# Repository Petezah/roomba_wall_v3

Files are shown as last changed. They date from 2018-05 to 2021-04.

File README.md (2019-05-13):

# roomba_wall_v3

An AVR device, based on ATTiny45, to transmit a virtual wall signal for an iRobot Roomba

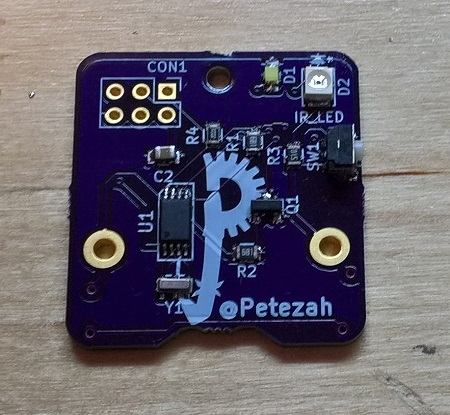
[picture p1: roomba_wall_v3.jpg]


## Folder layout

* /firmware
  * Source for the ATTiny45 firmware
* /hardware
  * Files describing the board layout, etc

## Building

### Prerequisites for "happy path":

* An AVR programmer
  * If you don't have one, you can build mine: https://oshpark.com/shared_projects/O24XLDbo
  * Though, this is a chicken-egg problem.  You can always program the programmer with an Arduino or a Raspberry Pi.
* AVR-GCC installed
  *  Easiest way to get this is 'sudo apt-get install arduino'
* A 6-position, dual-row IDC cable
* A 6-position, dual-row, male header to either:
  * Solder onto your board for programming, or
  * Plug into the IDC cable and "wedge" it into the ISP header during programming (recommended, and is what I do)

### Steps

#### hardware

* Order a board based on the files in https://github.com/Petezah/roomba_wall_v3/tree/master/hardware
  * Alternately, order one directly from OSH Park here: https://oshpark.com/shared_projects/i2FdXslA
* Purchase parts from [Mouser electronics](http://mouser.com) using the current BOM
  * Use the ones with "mouser" in their filenames
* Assemble the board--part references are all marked on the silkscreen
  * NB: The ISP header should not be soldered to the board--merely insert the header pins into the IDC cable and wedge the pins into the vias during programming

#### firmware

There are two methods to wire the board for programming:

* *Recommended way*:
  *  Order my AVR programmer board here: https://oshpark.com/shared_projects/O24XLDbo
  *  Assemble, and use an IDC cable as described above

* Alternate way: 
  *  Order my Raspberry Pi ISP board here: https://oshpark.com/shared_projects/iYtnPahC
  * Or hook up the ISP pins on the assembled board to your Raspberry PI as follows:
    * ISP Pin 1 --> Raspberry Pi Pin 21 (MISO)
    * ISP Pin 2 --> Raspberry Pi Pin 17 (3.3V)
    * ISP Pin 3 --> Raspberry Pi Pin 23 (SCK)
    * ISP Pin 4 --> Raspberry Pi Pin 19 (MOSI)
    * ISP Pin 5 --> Raspberry Pi Pin 15 (GPIO22)
    * ISP Pin 6 --> Raspberry Pi Pin 25 (GND)

Once wiring is accomplished:
* Execute the following on the Raspberry Pi command line
  * cd firmware
  * make fuse
  * make install

## Operating

There are a few different ways to operate this device.

### Default (easy) timed mode

When the device is off (sleeping), simply press and release the button once.  The device will respond by turning the indicator LED on for one second and then turning it off.  After this, the device will operate for 3 hours and then go to sleep again.

### Custom timed mode

When the device is off (sleeping), hold down the button.  The device will blink briefly, once every half second.  Every blink corresponds to 15 minutes of operation.  For example, if you want the device to operate for 30 minutes, you will wait for 2 blinks; or, if you want the device to operate for 1 hour and 15 minutes, you will wait for 5 blinks.  Once you reach the desired count, release the button.  The device will then wait, and will then blink the LED indicator the number of times it has counted for the running time.  After this, the device will run for the set time, and then will go to sleep.

### Turning off the device (putting it to sleep manually)

When the device is operating, hold down the button for two seconds.  The device will blink 3 times rapidly.  Now release the button, and the device will blink 2 times rapidly, and will then go to sleep.

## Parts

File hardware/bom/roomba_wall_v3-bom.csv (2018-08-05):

Reference | Value | Footprint | Datasheet
U1 | ATTINY45-20SU | lib_fp:ATtiny45V-10XU-TSSOP-8
Y1 | 8Mhz | lib_fp:Resonator_SMD_muRata_CSTCE_G-3pin_3.0x0.7mm
R1 | 560 | lib_fp:R_0805
R2 | 560 | lib_fp:R_0805
R3 | 51 | lib_fp:R_0805
D1 | LED | lib_fp:LED_0805
D2 | IR_LED | kicad-libs:VSMB3940X01-GS08
CON1 | AVR-ISP-6 | lib_fp:Pin_Header_Straight_2x03_Pitch2.54mm
C2 | 10uF | lib_fp:C_0805
Q1 | Q_NPN_BEC | lib_fp:SOT-23
BT1 | Battery_Cell | lib_fp:CR2032-THRU
SW1 | Button | lib_fp:e-switch-TL-3340-AF160QG
R4 | 10k | lib_fp:R_0805

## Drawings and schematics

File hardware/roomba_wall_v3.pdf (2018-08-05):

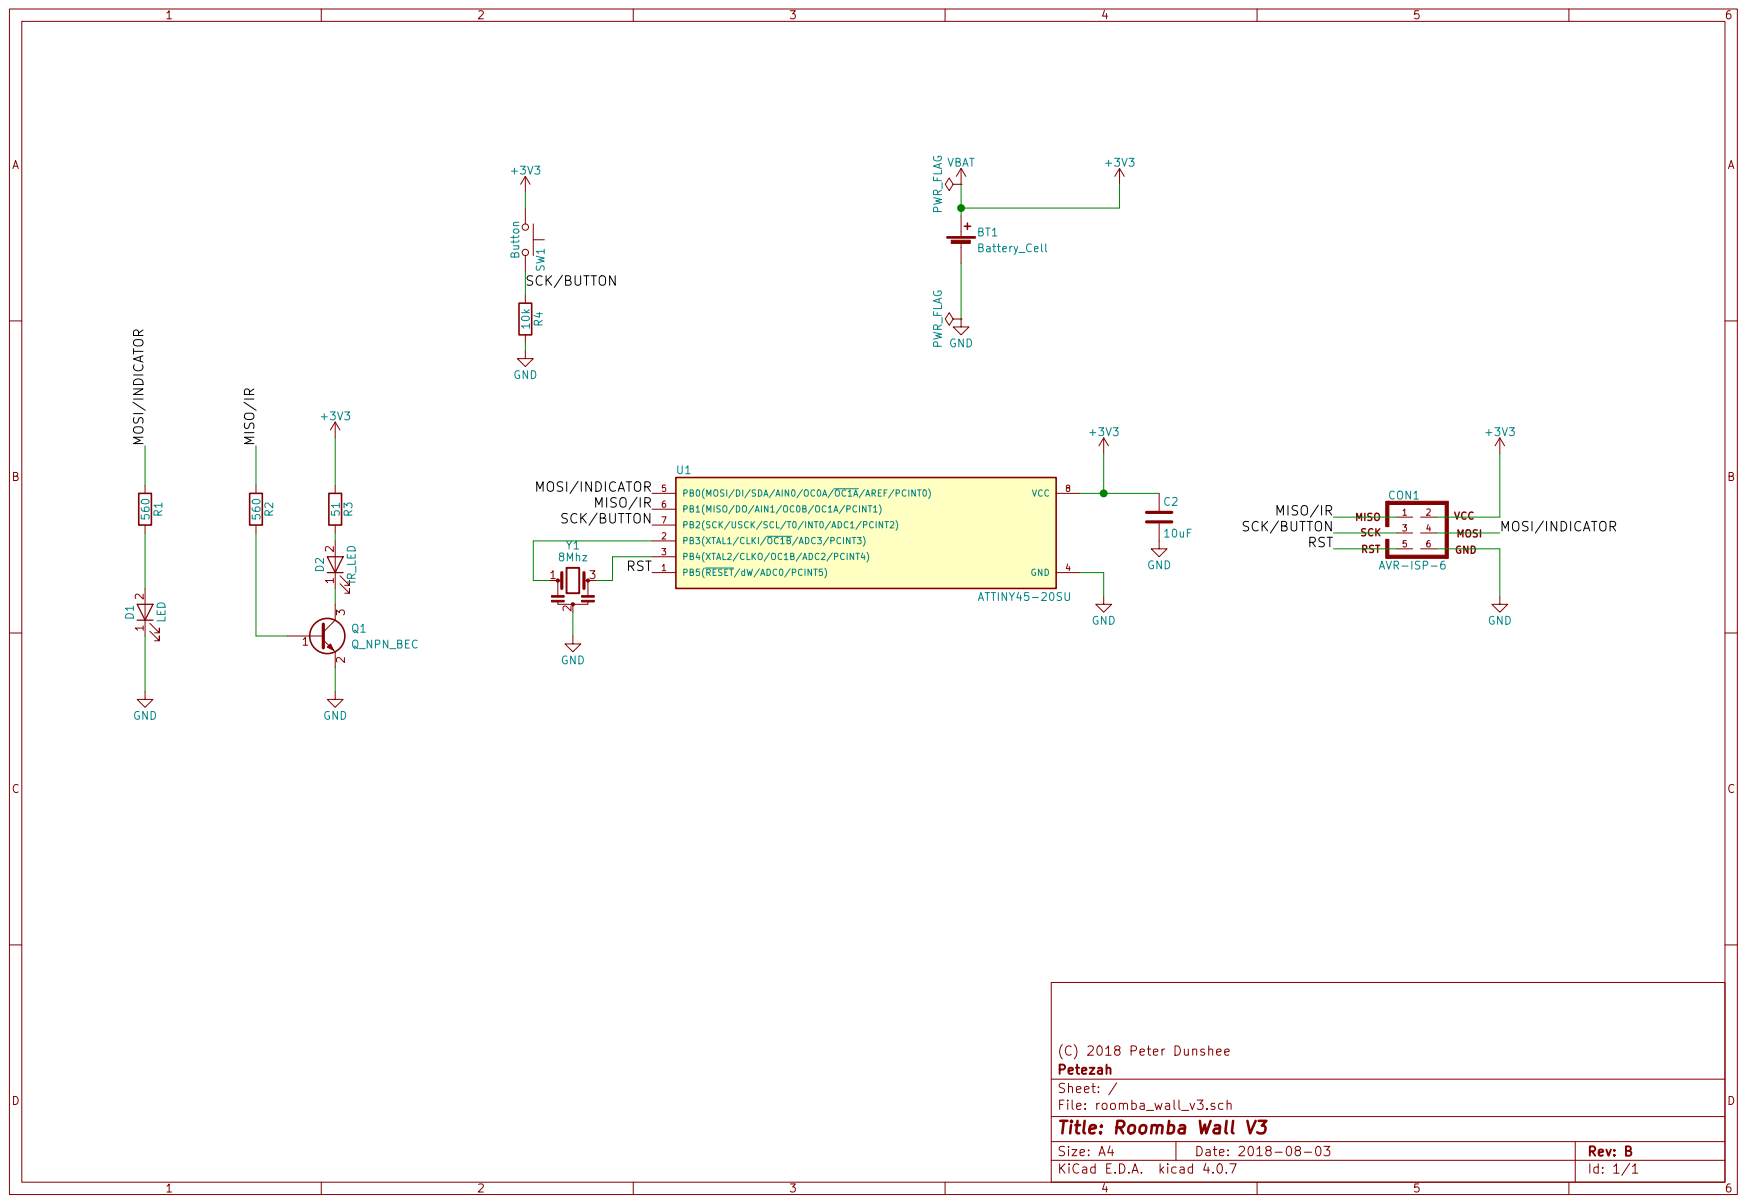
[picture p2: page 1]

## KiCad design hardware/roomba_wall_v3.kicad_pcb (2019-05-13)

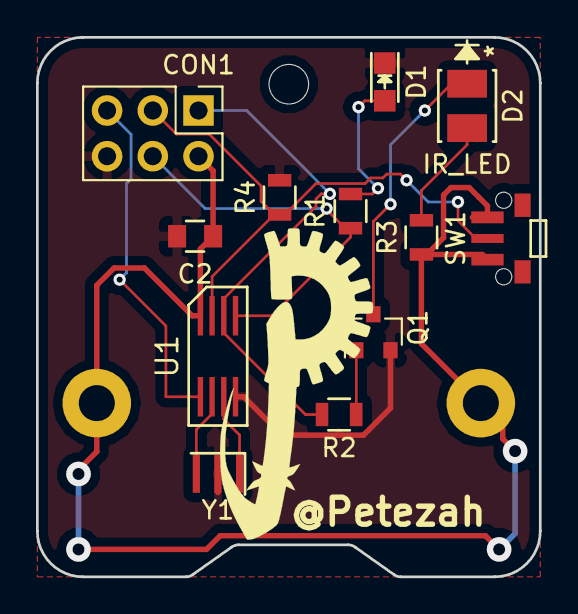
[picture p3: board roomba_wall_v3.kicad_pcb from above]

Board: 2 copper layers, 27.9 x 30.0 mm, 13 parts (1 on the bottom side), 12 nets.

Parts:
BT1: Battery_Cell; CR2032-THRU
C2: 10uF; C_0805
CON1: AVR-ISP-6; Pin_Header_Straight_2x03_Pitch2.54mm
D1: LED; LED_0805
D2: IR_LED; VSMB3940X01-GS08
Q1: Q_NPN_BEC; SOT-23
R1, R2: 560; R_0805
R3: 51; R_0805
R4: 10k; R_0805
SW1: Button; e-switch-TL-3340-AF160QG
U1: ATTINY45-20SU; ATtiny45V-10XU-TSSOP-8
Y1: 8Mhz; Resonator_SMD_muRata_CSTCE_G-3pin_3.0x0.7mm

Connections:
+3V3: BT1.1, C2.1, CON1.2, R3.1, SW1.1, U1.8
/MISO/IR: CON1.1, R2.1, U1.6
/MOSI/INDICATOR: CON1.4, R1.1, U1.5
/RST: CON1.5, U1.1
/SCK/BUTTON: CON1.3, R4.1, SW1.2, U1.7
GND: BT1.2, C2.2, CON1.6, D1.1, Q1.2, R4.2, U1.4, Y1.2
unnamed: D1.2, R1.2
unnamed: D2.1, Q1.3
unnamed: D2.2, R3.2
unnamed: Q1.1, R2.2
unnamed: U1.2, Y1.1
unnamed: U1.3, Y1.3

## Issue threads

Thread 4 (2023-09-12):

No BOM for mouser

ahshah, 2023-09-12:
Hi, thanks for making this project available to us- there is no mouser BOM, and the CSV in the bom folder does not contain part numbers. Would this be a mistaken omission or am i reading the readme incorrectly?
Thanks!

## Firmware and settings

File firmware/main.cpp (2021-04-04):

/*
 * roomba_wall_v2.cpp
 *
 * Created: 5/11/2016 9:12:04 PM
 * Author : Peter Dunshee
 */

#include "roomba_wall_v3.h"
#include <avr/io.h>
#include <avr/power.h>
#include <avr/interrupt.h>
#include <avr/sleep.h>
#include <avr/wdt.h>
#include <util/delay.h>

enum run_state
{
	RS_Sleeping = 0,	// device sleeping
	RS_Running,			// running, normal
	RS_RunningShutdown, // running, in possible shut-down process
	RS_ShuttingDown,	// shutdown initiated, debouncing switch before sleep
	RS_InitCounter,		// start-up, init the counter process
	RS_Counter,			// running the counter process
	RS_TimeSet			// setting the timer, proceeds to running state
};
volatile run_state g_state = RS_Sleeping;   // current state-machine state
volatile uint32_t g_timerTicks = 0;			// number of TIMER1 ticks since power-on
volatile uint32_t g_lastTimerTicks = 0;		// used to time operations in various places
volatile int g_counter = 0;					// saves the state-counter value between iterations
volatile uint8_t g_debounceDownCounter = 0; // how long the button has been depressed
volatile uint8_t g_debounceUpCounter = 0;   // how long the button has been released
volatile uint8_t g_setTimeCount = 0;		// records the number of time units the user has set the device to run for

#ifdef HALF_HOUR_PER_BLINK
#define NUM_TIMER_TICKS_PER_PRESS 3600; // run for 1/2hr per setting: 3600 = 60s * 30m * 2, since 1 tick per .5s
#else									// QUARTER_HOUR_PER_BLINK
#define NUM_TIMER_TICKS_PER_PRESS 1800; // run for 1/4hr per setting: 1800 = 60s * 15m * 2, since 1 tick per .5s
#endif
#define DEFAULT_NUM_TICKS_UNTIL_DISABLED (2 /*hours*/ * 60 /*minutes*/ * 60 /*seconds*/ * 2 /*seconds per tick*/)
volatile int g_numTicksUntilDisabled = 0;

#ifdef ROOMBA_WALL_V2
#define IR_TX_DELAY 50000
#elif ROOMBA_WALL_V3
#define IR_TX_DELAY 25000
#else // others (eg. Christmas barrier)
#define IR_TX_DELAY 10000
#endif

// 4s watchdog timeout
#define ROOMBA_WALL_WDT_VALUE WDTO_4S

void sleep_until_interrupt()
{
	wdt_disable();      // disable watchdog
	MCUCR |= _BV(SE);   // sleep enable bit
	GIMSK |= _BV(PCIE); // Enable pin-change interrupts to wake us up
	sleep_mode();
	GIMSK &= ~_BV(PCIE); // Disable pin-change interrupts
	MCUCR &= ~_BV(SE);   // clear sleep enable bit
	wdt_enable(ROOMBA_WALL_WDT_VALUE);
}

void blink_led(uint8_t numTimes, bool fastDelay = false)
{
	PORTB &= ~_BV(0);
	for (uint8_t i = 0; i < numTimes; ++i)
	{
		if (fastDelay)
			_delay_ms(50);
		else
			_delay_ms(200);
		PORTB |= _BV(0); //on
		if (fastDelay)
			_delay_ms(50);
		else
			_delay_ms(200);
		PORTB &= ~_BV(0); //off
	}
}

int main(void)
{
	// Disable ADC; we don't need it, and it uses more power
	ACSR |= _BV(ACD); // analog comparator disable

	// Set up timer1 to trigger every 1/2 second
	TCCR1 |= _BV(CTC1);										// enable timer compare match CTC1
	TCCR1 |= _BV(CS13) | _BV(CS12) | _BV(CS11) | _BV(CS10); // set prescaler ck/16384 (1/(8Mhz/16384) = 2.048 ms)
	OCR1C = 244;											// count to 1/2 seconds (2.048ms * 244 = .5s)
	TIMSK |= _BV(OCIE1A);									// enable compare match irq

	// Set interrupt on PB2
	DDRB &= ~_BV(DDB2);					// PB2 set as input
	GIMSK |= _BV(INT0);					// enable PCIE interrupt
	PCMSK |= _BV(PCINT2);				// interrupt on PB2
	MCUCR |= (_BV(ISC01) | _BV(ISC00)); // enable rising edge (ISC01 and ISC00)
	MCUCR |= _BV(SM1);					// enable power-down for sleep (SM1)
	sei();								// enable interrupts

	// Red-Status LED
	DDRB |= _BV(0);   // Set PORTB pin 4 to digital output (equivalent to pinMode(0, OUTPUT))
	PORTB &= ~_BV(0); // Pin 0 set to LOW (equivalent to digitalWrite(0, LOW))

#ifdef ROOMBA_WALL_V3
	// Power down initially
	g_state = RS_Sleeping;
	sleep_until_interrupt();
#else
	g_state = RS_Running;
#endif

	g_counter = -1;
	int i = -1;
	uint32_t lastBlinkTick = 0;
	while (1)
	{
		wdt_reset();
		i = g_counter;
		switch (g_state)
		{
		case RS_Sleeping:
			g_setTimeCount = 0;
			sleep_until_interrupt();
			break;

		case RS_ShuttingDown:
			if (g_debounceUpCounter >= 2)
			{
				blink_led(2, true);
				g_state = RS_Sleeping;
				delay_ten_us(1000);
				g_debounceDownCounter = 0;
				g_debounceUpCounter = 0;
				i = 0;
			}
			break;

		case RS_RunningShutdown:
			// If the button has been pressed for more than 2 seconds,
			// blink, then shut down the device
			if (g_debounceDownCounter >= 4)
			{
				blink_led(3, true);
				g_state = RS_ShuttingDown;
				g_debounceUpCounter = 0;
				g_debounceDownCounter = 0;
				i = 0;
			}
			// If the button has been released long enough, revert to Running state
			if (g_debounceUpCounter >= 2)
			{
				g_state = RS_Running;
				g_debounceDownCounter = 0;
				g_debounceUpCounter = 0;
				i = 0;
			}
			// Fall through to RS_Running
		case RS_Running:
			if (g_numTicksUntilDisabled <= 0)
				g_state = RS_Sleeping;

			g_setTimeCount = 0;
			i++;
			if (i == 0)
				PORTB |= _BV(0); // digitalWrite(4, HIGH);
			if (i == 1)
				PORTB &= ~_BV(0); // digitalWrite(4, LOW);
			if (i == 5)
				i = -1;

			roomba_send(162); // Virtual Wall
			PORTB &= ~_BV(0); // digitalWrite(4, LOW);

			delay_ten_us(IR_TX_DELAY);
			break;
		case RS_InitCounter:
			// Initialize the time setter and proceed to the counter phase
			g_state = RS_Counter;
			lastBlinkTick = g_lastTimerTicks;
			break;

		case RS_Counter:
			i++;
			// If it has been more than 1 second (1 tick == .5s)
			// indicate to the user that another "count" has happened
			if (g_timerTicks - lastBlinkTick >= 2)
			{
				lastBlinkTick = g_timerTicks;
				blink_led(1, true);
			}
			// If the button has been released for more than 1 second,
			// proceed to time-setting phase based on our current count
			if (g_debounceUpCounter >= 2)
			{
				g_setTimeCount = (g_timerTicks - g_lastTimerTicks) / 2;
				g_setTimeCount--; // adjust for fudge-error
				g_state = RS_TimeSet;
				i = 0;
			}
			break;

		case RS_TimeSet:
			if (g_setTimeCount < 1)
			{
				// Button was pressed and released; merely start the default timer
				g_numTicksUntilDisabled = DEFAULT_NUM_TICKS_UNTIL_DISABLED;
				g_state = RS_Running;

				// Turn on the LED for 1 second to indicate success of default state
				PORTB |= _BV(0); //on
				_delay_ms(1000);
				PORTB &= ~_BV(0); //off
				break;
			}

			i++;
			if (i >= 2) // 2 seconds
			{
				i = -1;
				g_state = RS_Running;
				blink_led(g_setTimeCount); // Indicate to the user how much time we have been actually set for
			}
			_delay_ms(2000);
			g_numTicksUntilDisabled = g_setTimeCount * NUM_TIMER_TICKS_PER_PRESS;
			break;
		} //switch

		g_counter = i;
	}
}

ISR(PCINT0_vect)
{
	// do nothing
}

ISR(INT0_vect)
{
	// If we are running, the button will turn off the device
	if (g_state == RS_Running)
	{
		g_counter = 0;
		g_debounceDownCounter = 0;
		g_debounceUpCounter = 0;
		g_lastTimerTicks = g_timerTicks;
		g_state = RS_RunningShutdown;
	}
	// If we are not already initializing or starting the
	// timer-set counter, then initialize the timer-setter
	else if (g_state != RS_InitCounter && g_state != RS_Counter && g_state != RS_RunningShutdown)
	{
		g_counter = 0;
		g_debounceDownCounter = 0;
		g_debounceUpCounter = 0;
		g_lastTimerTicks = g_timerTicks;
		g_state = RS_InitCounter;
	}
	PORTB &= ~_BV(0);
}

ISR(TIMER1_COMPA_vect)
{
	g_timerTicks++;
	g_numTicksUntilDisabled--;
	if (PINB & _BV(PB2))
		g_debounceDownCounter++;
	else
		g_debounceUpCounter++;
}

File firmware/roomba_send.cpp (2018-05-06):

/*

Send infrared commands from the Arduino to the iRobot Roomba
by probono

2013-03-17 Initial release

Copyright (c) 2013 by probono
All rights reserved.

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
1. Redistributions of source code must retain the above copyright notice, this
list of conditions and the following disclaimer.
2. Redistributions in binary form must reproduce the above copyright notice,
this list of conditions and the following disclaimer in the documentation
and/or other materials provided with the distribution.

THIS SOFTWARE IS PROVIDED BY THE COPYRIGHT HOLDERS AND CONTRIBUTORS "AS IS" AND
ANY EXPRESS OR IMPLIED WARRANTIES, INCLUDING, BUT NOT LIMITED TO, THE IMPLIED
WARRANTIES OF MERCHANTABILITY AND FITNESS FOR A PARTICULAR PURPOSE ARE
DISCLAIMED. IN NO EVENT SHALL THE COPYRIGHT OWNER OR CONTRIBUTORS BE LIABLE FOR
ANY DIRECT, INDIRECT, INCIDENTAL, SPECIAL, EXEMPLARY, OR CONSEQUENTIAL DAMAGES
(INCLUDING, BUT NOT LIMITED TO, PROCUREMENT OF SUBSTITUTE GOODS OR SERVICES;
LOSS OF USE, DATA, OR PROFITS; OR BUSINESS INTERRUPTION) HOWEVER CAUSED AND
ON ANY THEORY OF LIABILITY, WHETHER IN CONTRACT, STRICT LIABILITY, OR TORT
(INCLUDING NEGLIGENCE OR OTHERWISE) ARISING IN ANY WAY OUT OF THE USE OF THIS
SOFTWARE, EVEN IF ADVISED OF THE POSSIBILITY OF SUCH DAMAGE.

IR Remote Control
129 Left
130 Forward
131 Right
132 Spot
133 Max
134 Small
135 Medium
136 Large / Clean
137 Stop
138 Power
139 Arc Left
140 Arc Right
141 Stop

Scheduling Remote
142 Download
143 Seek Dock

Roomba Discovery Driveon Charger
240 Reserved
248 Red Buoy
244 Green Buoy
242 Force Field
252 Red Buoy and Green Buoy
250 Red Buoy and Force Field
246 Green Buoy and Force Field
254 Red Buoy, Green Buoy and Force

Roomba 500 Drive-on Charger
160 Reserved
161 Force Field
164 Green Buoy
165 Green Buoy and Force Field
168 Red Buoy
169 Red Buoy and Force Field
172 Red Buoy and Green Buoy
173 Red Buoy, Green Buoy and Force Field

Roomba 500 Virtual Wall
162 Virtual Wall

Roomba 500 Virtual Wall Lighthouse ###### (FIXME: not yet supported here)
0LLLL0BB
LLLL = Virtual Wall Lighthouse ID
(assigned automatically by Roomba
560 and 570 robots)
1-10: Valid ID
11: Unbound
12-15: Reserved
BB = Which Beam
00 = Fence
01 = Force Field
10 = Green Buoy
11 = Red Buoy

*/

#include "roomba_wall_v3.h"

void roomba_send(int code)
{
	const int length = 8;
	unsigned int raw[length * 2];
	unsigned int one_pulse = 3000;
	unsigned int one_break = 1000;
	unsigned int zero_pulse = one_break;
	unsigned int zero_break = one_pulse;

	int arrayposition = 0;
	// Serial.println("");
	for (int counter = length - 1; counter >= 0; --counter)
	{
		if (code & (1 << counter))
		{
			// Serial.print("1");
			raw[arrayposition] = one_pulse;
			raw[arrayposition + 1] = one_break;
		}
		else
		{
			// Serial.print("0");
			raw[arrayposition] = zero_pulse;
			raw[arrayposition + 1] = zero_break;
		}
		arrayposition = arrayposition + 2;
	}
	for (int i = 0; i < 3; i++)
	{
		sendRawIR(raw, 15, 38); //irsend.sendRaw(raw, 15, 38);  // Based on IRRemote library
		delay_ten_us(5000);			//50ms = 50000us
	}
	//Serial.println("");
}

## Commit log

2018-02-24 Allow the wake time to be set via a button hold
2018-02-25 Start v3 PCB project
    [roomba_wall_v2.brd, roomba_wall_v2.sch, roomba_wall_v2_c.brd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]
2018-02-25 Start v3 hardware from the Christmas tree barrier point
    [christmas_tree_barrier-B.Cu.gbr, christmas_tree_barrier-B.Mask.gbr, christmas_tree_barrier-B.Paste.gbr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]
2018-02-28 Schematic for v3 Added a user button mostly Changed to a switch and a battery, like v2 (from Christmas Barrier)
    [roomba_wall_v3.sch]
2018-02-28 Progress on annotating and reassigning footprints I want to use 0805, since they seem the easiest and cheapest to source
    [roomba_wall_v3.sch]
2018-03-03 Updated footprint associations, etc for v3
    [roomba_wall_v3.kicad_pcb, roomba_wall_v3.sch]
2018-03-03 Fix fp archive pointers
    [roomba_wall_v3.kicad_pcb, roomba_wall_v3.sch]
2018-03-03 Fix all ERC errors
    [roomba_wall_v3.kicad_pcb, roomba_wall_v3.sch]
2018-03-21 Placed and routed new PCB layout
    [roomba_wall_v3.kicad_pcb, roomba_wall_v3.sch]
2018-03-21 Refill zones
    [roomba_wall_v3.kicad_pcb]
2018-04-15 Added a mounting hole for hanging and finalized layout for rev A Also exported gerbers
    [roomba_wall_v3-B.Cu.gbl, roomba_wall_v3-B.Mask.gbs, roomba_wall_v3-B.Paste.gbp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]
2018-04-16 Update README and footprint lib archive
    [roomba_wall_v2.fzz]
2018-04-16 Schematic plot
2018-04-16 Exported basic BOM
    [roomba_wall_v3-bom.csv]
2018-05-06 Tweak delays * 15 minutes runtime per LED blink * 30000 delay per IR TX
2018-08-03 Working on rev B
    [roomba_wall_v3.kicad_pcb, roomba_wall_v3.sch]
2018-08-05 Finished rev-b layout Updated gerbers Updated BOM Updated footprint archive Updated PDF schematic plot
    [roomba_wall_v3-B.Cu.gbl, roomba_wall_v3-B.Mask.gbs, roomba_wall_v3-B.Paste.gbp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]
2018-08-20 New behavior: * 1 quick press -> on for default period (3 hours) * hold down -> set for 15 minutes per blink * from running, hold down for 2 seconds -> turn off
    long LED blink will indicate #1
    quick LED blinks will indicate #2, and amount of time running
    3 quick LED blinks will indicate #3, that device will turn off
2018-08-22 Fix bug in shutdown code If the user releases the button in shutdown mode before shutdown has occurred, the state should just revert to the running state. This will allow the button counters to retur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
    [main.cpp]
2019-01-21 Adjust fuse settings
2019-02-04 Upgraded to Kicad 5
    [roomba_wall_v3-2019-02-03-14-21-23.sch]
2019-05-02 Generate interactive BOM Move CSV BOM into folder
    [roomba_wall_v3-bom.csv]
2019-05-02 Update format
    [roomba_wall_v3.kicad_pcb]
2019-05-13 Updated gerbers
    [roomba_wall_v3-B.Cu.gbl, roomba_wall_v3-B.Mask.gbs, roomba_wall_v3-B.Paste.gbp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]
2019-05-13 Make shutdown more error-proof
    [main.cpp]
2021-04-04 Add a watchdog timer and change default time
    Add a watchdog timer to reset the device if it crashes.
    Change the "default" run time to 2 hours instead of 3
    [main.cpp]

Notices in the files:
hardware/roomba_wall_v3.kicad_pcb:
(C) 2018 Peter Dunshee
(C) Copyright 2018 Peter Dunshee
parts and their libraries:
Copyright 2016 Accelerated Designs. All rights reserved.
